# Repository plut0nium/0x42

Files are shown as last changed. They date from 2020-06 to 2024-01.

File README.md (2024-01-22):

# >__0x42___

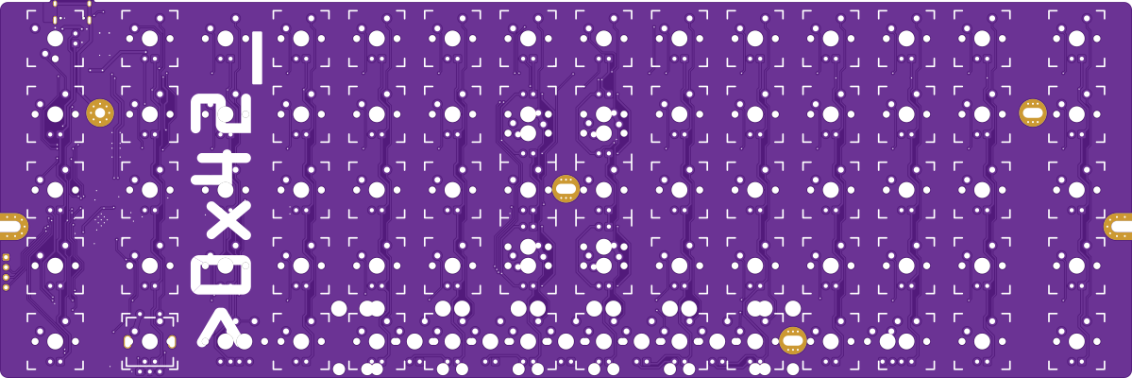
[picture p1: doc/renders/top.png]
0x42 top render

_Render generated by the [tracespace.io](https://tracespace.io/view/) site._

> **DISCLAIMER :**
> This PCB has been designed with Kicad6 and prototyped in late 2022.
> As of December 2023, I use Kicad7 and have converted the files to the new revised format.
> This is not expected to introduce any bug, but I do not offer any guarantee against it and provide the files AS-IS.
> You are therefore advised to perform an in-depth review of the design before manufacturing/assembly.

## Introduction
__0x42__ is an open-source 60% ortholinear keyboard PCB designed to fit the (_de facto_) standard 60% keyboard cases and use an ergo keycap set (1u alphas, with 1.5u modifiers and -optional- split 2u spacebars).

Heavily inspired by the [Boardwalk][boardwalk-url] (although the variety of supported layouts is much lower, see below), __0x42__ is based on a Raspberry Pi RP2040 (ARM) MCU with onboard USB-C connexion (or through a daughterboard), it allows the use of a rotary encoder and has a dedicated LED driver for in-switch backlight (monochrome).

## Features

 * MX-style switches
 * Standard 60% format
 * In-switch LED backlight using dedicated (_Lumissil_) LED driver
 * Rotary encoder
 * __No__ RGB underglow
 * USB Type-C with ESD protection _or_ USB daughterboard (through JST connector)
 * Powered by [QMK][qmk-url] (but could be ported to any other open-source MK firmware)

## Supported layouts

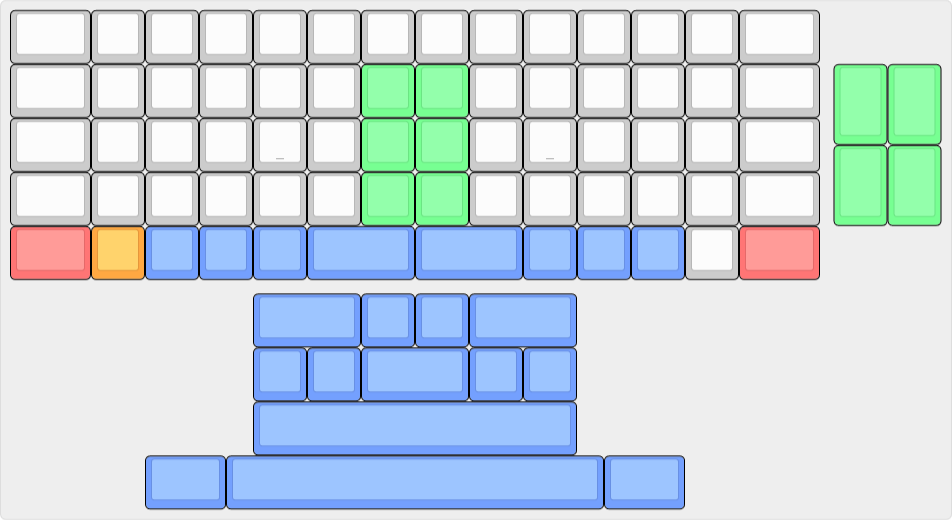
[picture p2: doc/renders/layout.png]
0x42 layouts

_Blue_ keys show some possible combinations of spacebars, _Orange_ can be replaced by rotary encoder, _Green_ are vertical (ergodox-like) 1.5u modifiers, and _Red_ are optional for HHKB-like layout.

## Keyboard cases

Please note that due to the ortholinear layout, some mounting holes on the PCB had to be moved (the 2 in the center part of the PCB), and consequently will not align with the standoffs commonly found in 60% tray-mount cases.
Only the 4 outer mounting holes are available in such situation.
This nevertheless results in a good fixation, particularly if using a switch plate, and should not be an issue for most users.

Other mounting types should not be affected.

## QMK Support

_TODO: add link to QMK repo_

## PCB Manufacturing & Assembly

### Panelization

[Kikit][kikit-url] can be used to produce a panelized PCB.

The included configuration in `0x42_panelize.json` will produce a single-board panel, i.e. adding a 10mm frame with tabs and mousebites.
This is not strictly required, but provides extra room for tooling holes, as well as order number placement.

```
kikit panelize -p 0x42_panelize.json 0x42.kicad_pcb panel/0x42_panel.kicad_pcb
```

### BOM

The schematic symbols have a "LCSC" property with LCSC/JLCPCB part # for suggested component reference.
As far as possible, JLCPCB _basic parts_ have been selected.
Some Kicad plugins make use of this information to extract a *.CSV BOM file that can be used for assembly.

There are many alternative references for compatible NOR flash chips, with varying capacity, from 8 to 32 Mbit or even more (note that RP2040 has a limit of 128Mbit/16MB)...

### JLCPCB

The [Kicad JLCPCB Tools][kicad-jlcpcb-url] plugin has been used to produce the required files (Gerber, drill, BOM & CPL) to have the board manufactured and assembled by JLCPCB. 

Kikit can also be used for this purpose, using `kikit fab`.

## License

CC-BY-SA 4.0

## Versions

 * __Rev 2__ _(work in progress)_ is almost identical to Rev 1, with MiniMELF diodes
 * __Rev 1__ is based on Raspberry Pi RP2040 MCU
 * __Rev 0__ is the original design and was based on a STM32F072 MCU

## Credits

 * [Boardwalk][boardwalk-url] by AlexAtPanc, Shensmobile & others... main source of inspiration for this layout
 * [Ai03][ai03-url], [Acheron Project/Gondolindrim][acheron-url], [ebastler][ebastler-url] for providing excellent opensource reference designs
 * and more generaly the mech keyboard community...

<!-- Markdwon links -->
[qmk-url]: https://qmk.fm/
[boardwalk-url]: https://panc.co/boardwalk
[ai03-url]: https://github.com/ai03-2725
[acheron-url]: https://github.com/AcheronProject
[ebastler-url]: https://github.com/ebastler
[kikit-url]: https://yaqwsx.github.io/KiKit/
[kicad-jlcpcb-url]: https://github.com/Bouni/kicad-jlcpcb-tools

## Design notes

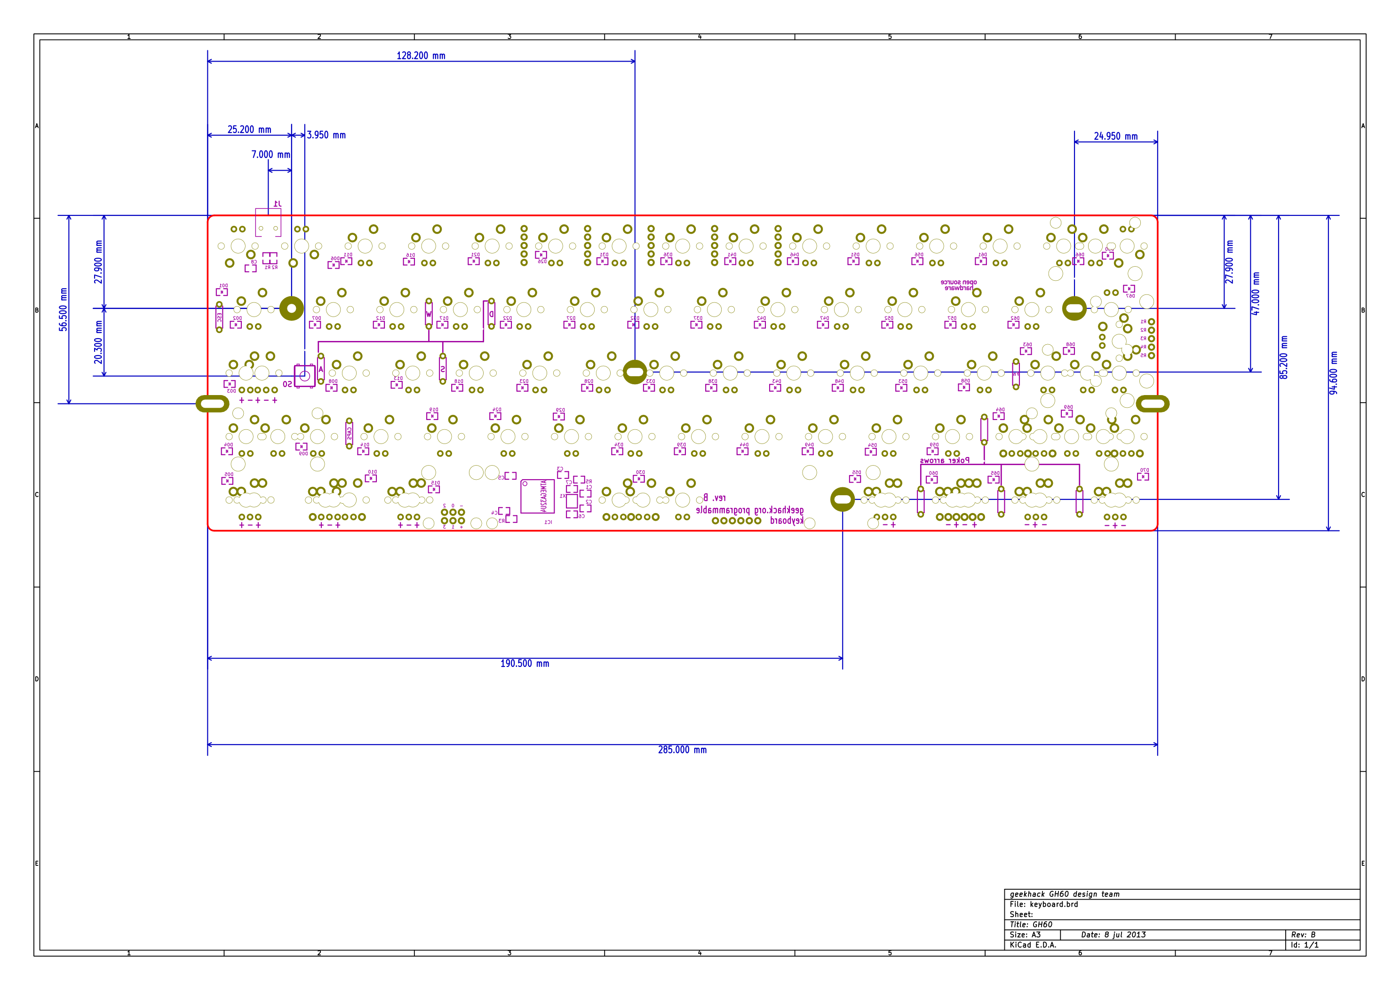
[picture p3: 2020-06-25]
doc/GH60_dimensions.png

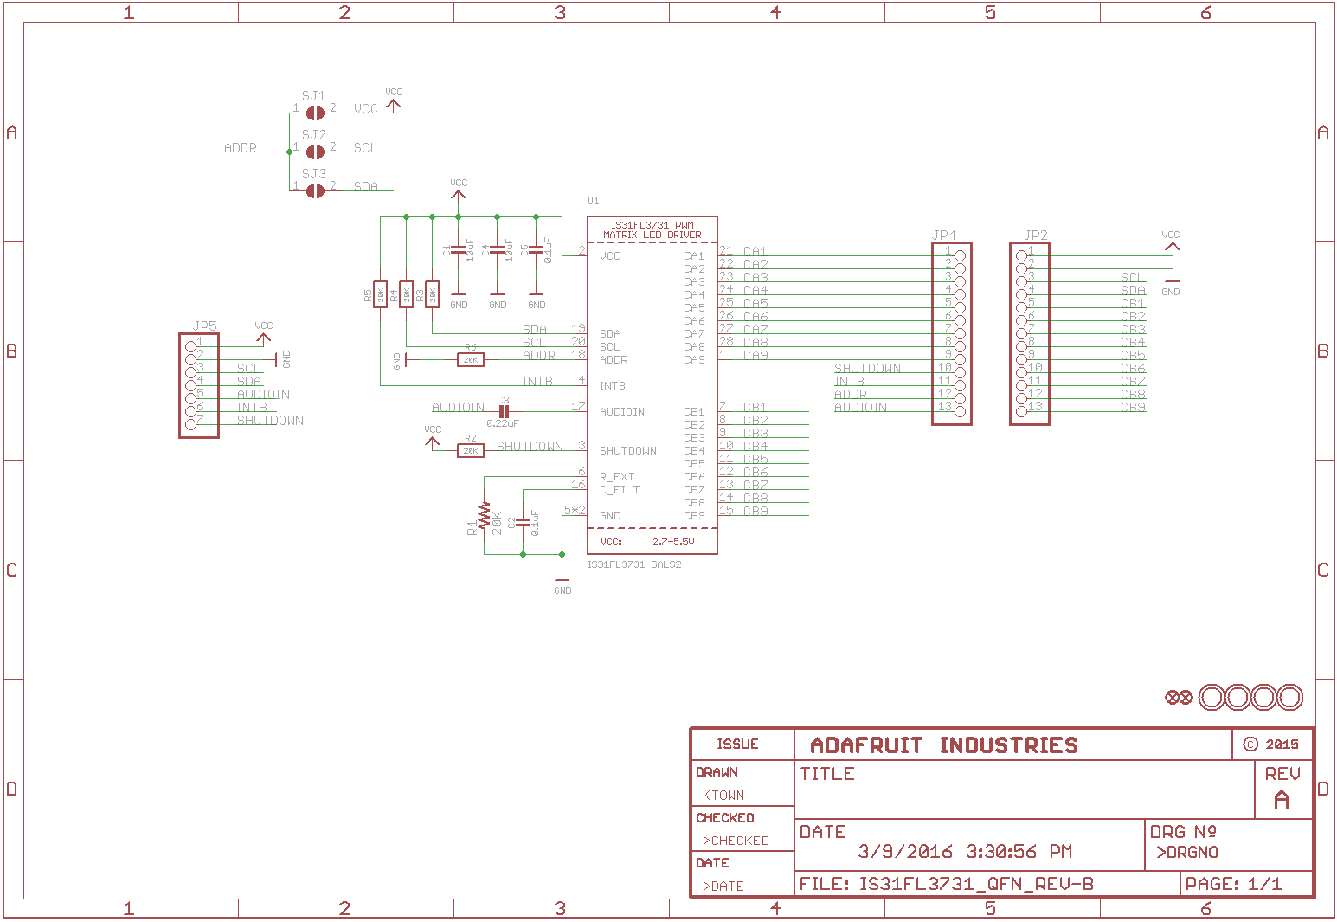
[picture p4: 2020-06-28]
doc/led_matrix_schem.png

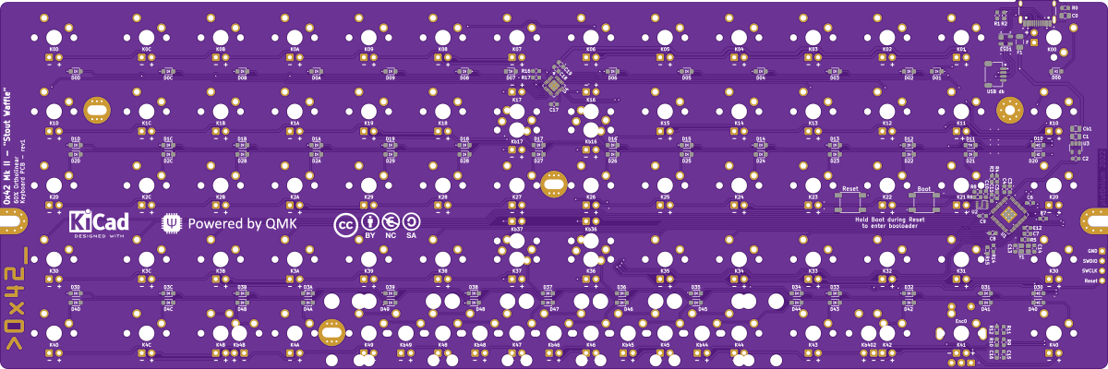
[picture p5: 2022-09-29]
doc/renders/bottom.png

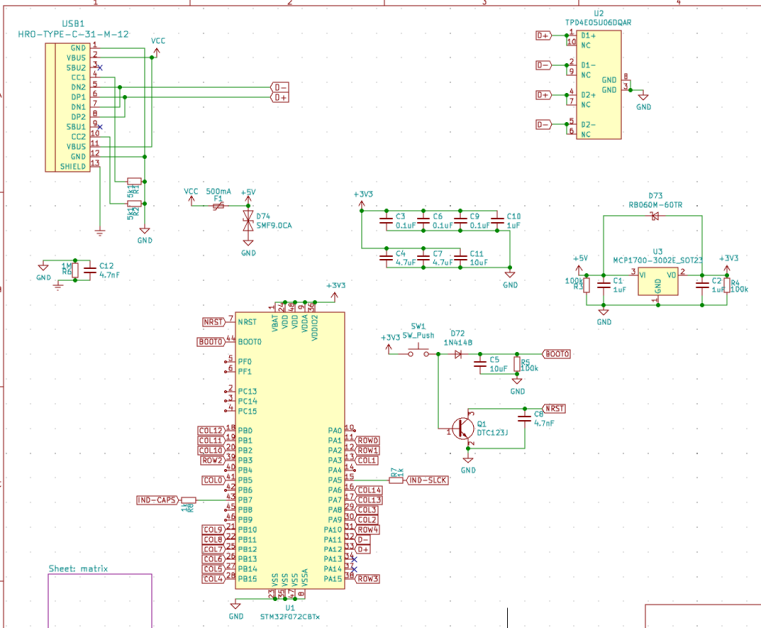
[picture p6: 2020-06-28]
doc/stm32_schem.png

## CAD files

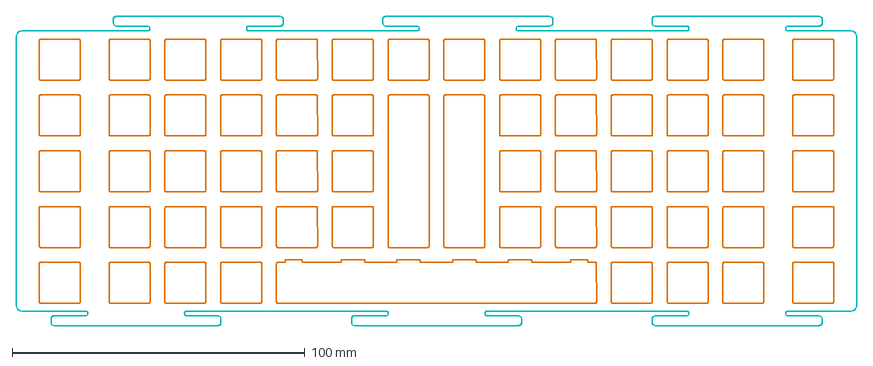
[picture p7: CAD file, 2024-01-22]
cad/plate_0x42_ALL.dxf
287.0 x 105.5 mm

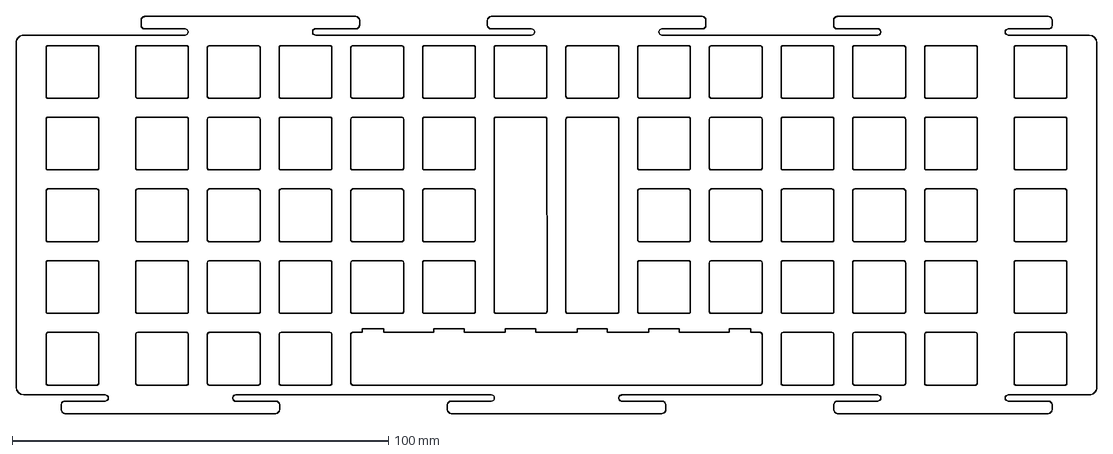
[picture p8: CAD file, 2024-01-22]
cad/plate_0x42_d60lite.dxf
287.0 x 105.5 mm

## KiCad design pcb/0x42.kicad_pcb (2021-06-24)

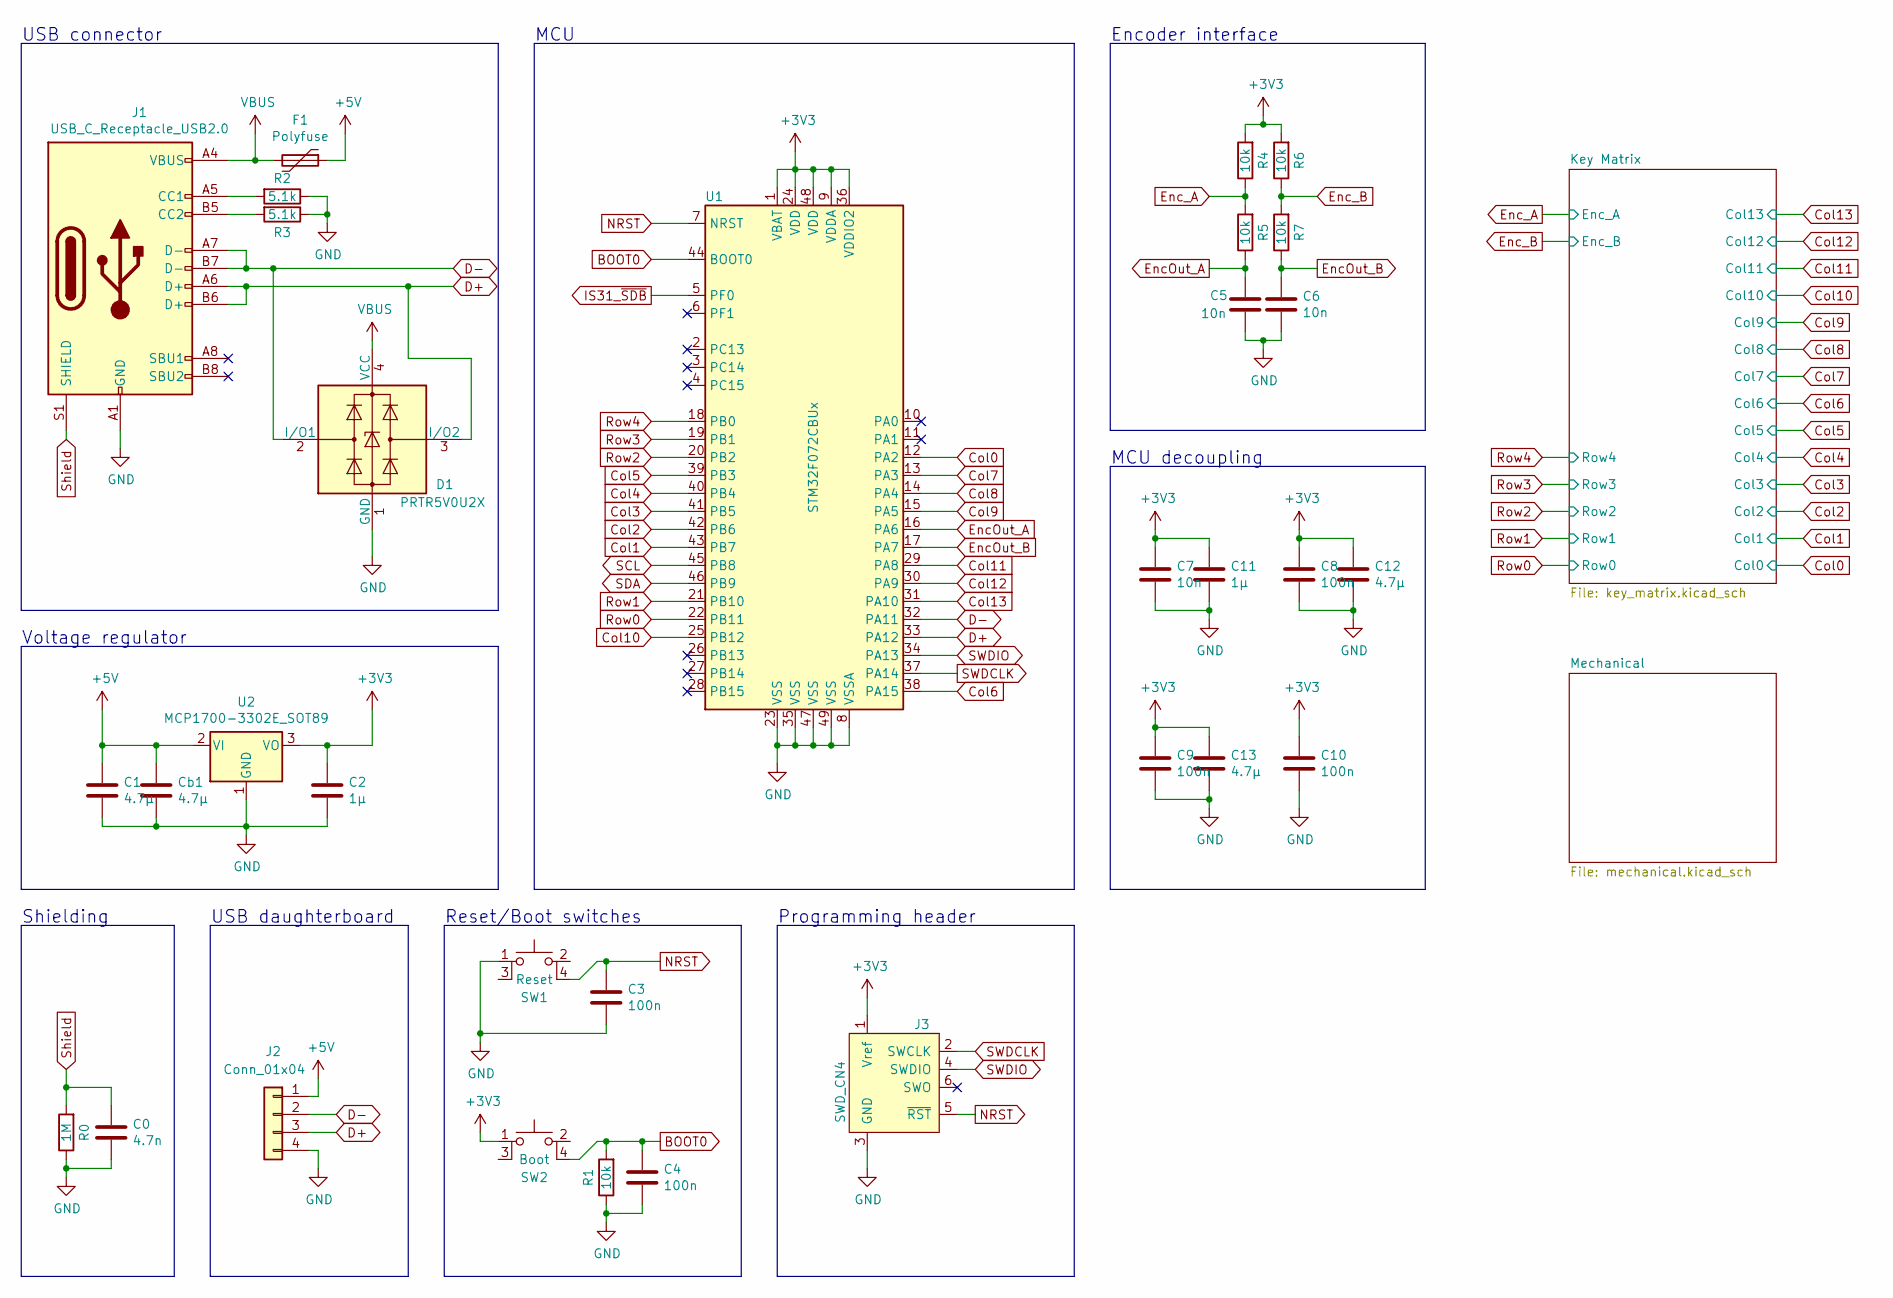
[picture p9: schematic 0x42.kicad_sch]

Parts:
C0: 4.7n; C_0805_2012Metric
C1: 4.7µ; C_0805_2012Metric
C2, C11: 1µ; C_0603_1608Metric
C3, C4, C8, C9, C10: 100n; C_0603_1608Metric
C5, C6, C7: 10n; C_0603_1608Metric
C12, C13: 4.7µ; C_0603_1608Metric
Cb1: 4.7µ; C_0805_2012Metric
D1: PRTR5V0U2X; SOT-143
F1: Polyfuse; Fuse_1206_3216Metric
J1: USB_C_Receptacle_USB2.0; USB_C_Receptacle_HRO_TYPE-C-31-M-12
J2: Conn_01x04; JST_SH_SM04B-SRSS-TB_1x04-1MP_P1.00mm_Horizontal
J3: SWD_CN4; SWD_1x06_P2.54mm_POGO
R0: 1M; R_0603_1608Metric
R1, R4, R5, R6, R7: 10k; R_0603_1608Metric
R2, R3: 5.1k; R_0603_1608Metric
SW1: Reset; TACT_SWITCH_5.2x5.2_4Pin
SW2: Boot; TACT_SWITCH_5.2x5.2_4Pin
U1: STM32F072CBUx; QFN-48-1EP_7x7mm_P0.5mm_EP5.6x5.6mm
U2: MCP1700-3302E_SOT89; SOT-89-3

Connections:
+3V3: C2.1, C7.1, C8.1, C9.1, C10.1, C11.1, C12.1, C13.1, J3.1 (Vref), R4.2, R6.2, SW2.1, U1.1 (VBAT), U1.9 (VDDA), U1.24 (VDD), U1.36 (VDDIO2), U1.48 (VDD), U2.3 (VO); also elsewhere on the board
+5V: C1.1, Cb1.1, F1.1, J2.1, U2.2 (VI); also elsewhere on the board
BOOT0: C4.1, R1.2, SW2.4, U1.44 (BOOT0)
Col0: U1.12 (PA2); also elsewhere on the board
Col1: U1.43 (PB7); also elsewhere on the board
Col2: U1.42 (PB6); also elsewhere on the board
Col3: U1.41 (PB5); also elsewhere on the board
Col4: U1.40 (PB4); also elsewhere on the board
Col5: U1.39 (PB3); also elsewhere on the board
Col6: U1.38 (PA15); also elsewhere on the board
Col7: U1.13 (PA3); also elsewhere on the board
Col8: U1.14 (PA4); also elsewhere on the board
Col9: U1.15 (PA5); also elsewhere on the board
Col10: U1.25 (PB12); also elsewhere on the board
Col11: U1.29 (PA8); also elsewhere on the board
Col12: U1.30 (PA9); also elsewhere on the board
Col13: U1.31 (PA10); also elsewhere on the board
D+: D1.3 (I/O2), J1.A6 (D+), J1.B6 (D+), J2.3, U1.33 (PA12)
D-: D1.2 (I/O1), J1.A7 (D-), J1.B7 (D-), J2.2, U1.32 (PA11)
EncOut_A: C5.1, R5.1, U1.16 (PA6)
EncOut_B: C6.1, R7.1, U1.17 (PA7)
Enc_A: R4.1, R5.2; also elsewhere on the board
Enc_B: R6.1, R7.2; also elsewhere on the board
GND: C0.2, C1.2, C2.2, C3.2, C4.2, C5.2, C6.2, C7.2, C8.2, C9.2, C10.2, C11.2, C12.2, C13.2, Cb1.2, D1.1 (GND), J1.A1 (GND), J1.A12 (GND), J1.B1 (GND), J1.B12 (GND), J2.4, J3.3 (GND), R0.1, R1.1, R2.1, R3.1, SW1.1, U1.8 (VSSA), U1.23 (VSS), U1.35 (VSS), U1.47 (VSS), U1.49 (VSS), U2.1 (GND); also elsewhere on the board
IS31_~SDB: U1.5 (PF0); also elsewhere on the board
NRST: C3.1, J3.5 (~RST), SW1.4, U1.7 (NRST)
unnamed: J1.A5 (CC1), R2.2
unnamed: J1.B5 (CC2), R3.2
RGB_DOUT: U1.28 (PB15); also elsewhere on the board
Row0: U1.22 (PB11); also elsewhere on the board
Row1: U1.21 (PB10); also elsewhere on the board
Row2: U1.20 (PB2); also elsewhere on the board
Row3: U1.19 (PB1); also elsewhere on the board
Row4: U1.18 (PB0); also elsewhere on the board
SCL: U1.45 (PB8); also elsewhere on the board
SDA: U1.46 (PB9); also elsewhere on the board
SWDCLK: J3.2 (SWCLK), U1.37 (PA14)
SWDIO: J3.4 (SWDIO), U1.34 (PA13)
Shield: C0.1, J1.S1 (SHIELD), R0.2; also elsewhere on the board
VBUS: D1.4 (VCC), F1.2, J1.A4 (VBUS), J1.A9 (VBUS), J1.B4 (VBUS), J1.B9 (VBUS)

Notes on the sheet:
USB daughterboard
Reset/Boot switches
Encoder interface
Programming header
MCU decoupling
MCU
Voltage regulator
USB connector
Shielding

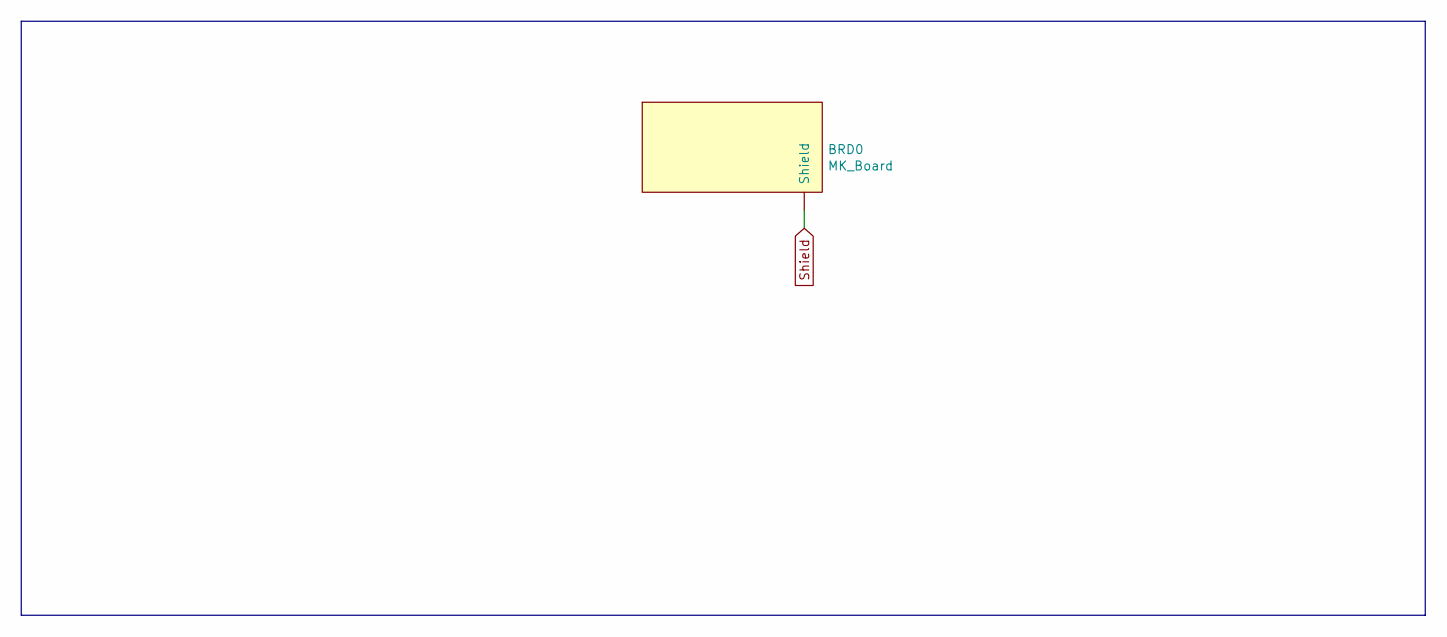
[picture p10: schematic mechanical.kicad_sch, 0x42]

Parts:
BRD0: MK_Board; 60_Outline_Ortho

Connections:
Shield: BRD0.1; also elsewhere on the board

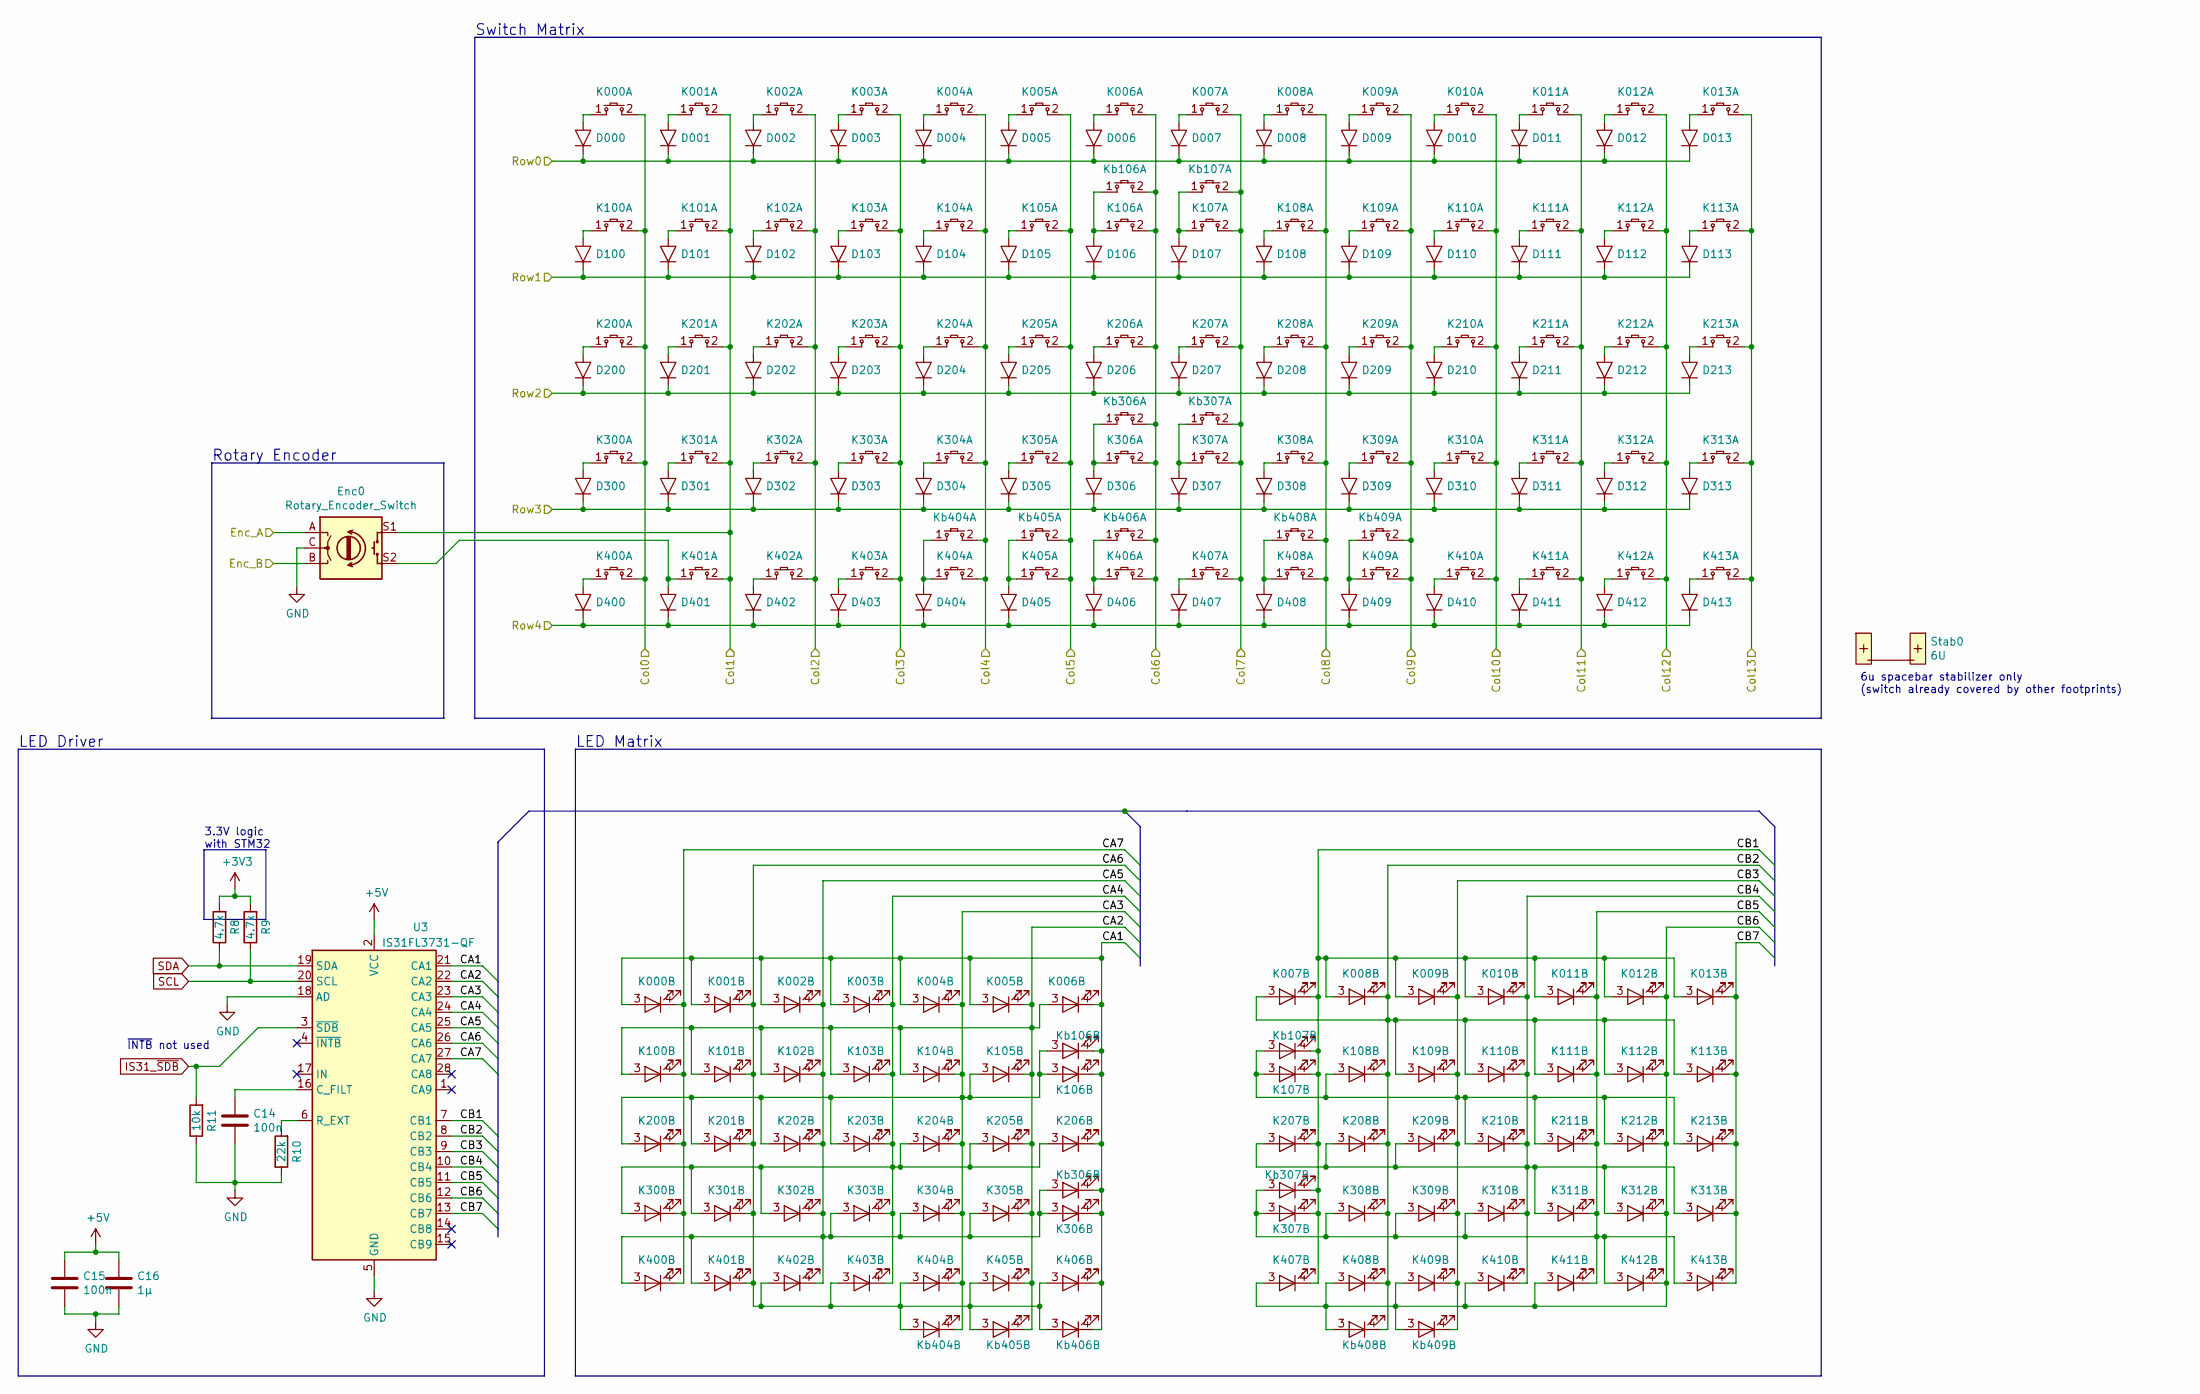
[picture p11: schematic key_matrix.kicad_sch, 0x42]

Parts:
C14, C15: 100n; C_0603_1608Metric
C16: 1µ; C_0603_1608Metric
D000, D001, D002, D003, D004, D005, D006, D007, D008, D009, D010, D011, D012, D013, D100, D101, D102, D103, D104, D105, D106, D107, D108, D109, D110, D111, D112, D113, D200, D201, D202, D203, D204, D205, D206, D207, D208, D209, D210, D211, D212, D213, D300, D301, D302, D303, D304, D305, D306, D307, D308, D309, D310, D311, D312, D313, D400, D401, D402, D403, D404, D405, D406, D407, D408, D409, D410, D411, D412, D413: Diode; D_SOD-323
Enc0: Rotary_Encoder_Switch; RotaryEncoder_Alps_EC11E-Switch_Vertical
K000: 1.5U; MXOnly-1.5U-Vertical-Flipped
K001, K002, K003, K004, K005, K006, K007, K008, K009, K010, K011, K012, K101, K102, K103, K104, K105, K108, K109, K110, K111, K112, K201, K202, K203, K204, K205, K206, K207, K208, K209, K210, K211, K212, K301, K302, K303, K304, K305, K306, K307, K308, K309, K310, K311, K312, K401, K402, K403, K404, K405, K406, K407, K408, K409, K410, K411, K412: 1U; MXOnly-1U
K013, K100, K113, K200, K213, K300, K313, K400, K413: 1.5U; MXOnly-1.5U
K106, K107: 1U; MXOnly-1U-Flipped
Kb106, Kb107: 1.5U; MXOnly-1.5U-Vertical
Kb306, Kb307: 1.5U; MXOnly-1.5U-Vertical-Flipped
Kb404, Kb405, Kb406, Kb408, Kb409: 2U; MXOnly-2U-ReversedStabilizers
R8, R9: 4.7k; R_0603_1608Metric
R10: 22k; R_0603_1608Metric
R11: 10k; R_0603_1608Metric
Stab0: 6U; MXOnly-6U-ReversedStabilizersOnly
U3: IS31FL3731-QF; QFN-28-1EP_4x4mm_P0.4mm_EP2.3x2.3mm

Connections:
+3V3: R8.2, R9.2; also elsewhere on the board
+5V: C15.1, C16.1, U3.2 (VCC); also elsewhere on the board
/Key Matrix/CA1: K000.3 (A), K001.3 (A), K002.3 (A), K003.3 (A), K004.3 (A), K005.3 (A), K006.4 (K), K106.4 (K), K206.4 (K), K306.4 (K), K406.4 (K), Kb106.4 (K), Kb306.4 (K), Kb406.4 (K), U3.21 (CA1)
/Key Matrix/CA2: K005.4 (K), K006.3 (A), K100.3 (A), K101.3 (A), K102.3 (A), K103.3 (A), K104.3 (A), K105.4 (K), K205.4 (K), K305.4 (K), K405.4 (K), Kb405.4 (K), U3.22 (CA2)
/Key Matrix/CA3: K004.4 (K), K104.4 (K), K105.3 (A), K106.3 (A), K200.3 (A), K201.3 (A), K202.3 (A), K203.3 (A), K204.4 (K), K304.4 (K), K404.4 (K), Kb106.3 (A), Kb404.4 (K), U3.23 (CA3)
/Key Matrix/CA4: K003.4 (K), K103.4 (K), K203.4 (K), K204.3 (A), K205.3 (A), K206.3 (A), K300.3 (A), K301.3 (A), K302.3 (A), K303.4 (K), K403.4 (K), U3.24 (CA4)
/Key Matrix/CA5: K002.4 (K), K102.4 (K), K202.4 (K), K302.4 (K), K303.3 (A), K304.3 (A), K305.3 (A), K306.3 (A), K400.3 (A), K401.3 (A), K402.4 (K), Kb306.3 (A), U3.25 (CA5)
/Key Matrix/CA6: K001.4 (K), K101.4 (K), K201.4 (K), K301.4 (K), K401.4 (K), K402.3 (A), K403.3 (A), K404.3 (A), K405.3 (A), K406.3 (A), Kb404.3 (A), Kb405.3 (A), Kb406.3 (A), U3.26 (CA6)
/Key Matrix/CA7: K000.4 (K), K100.4 (K), K200.4 (K), K300.4 (K), K400.4 (K), U3.27 (CA7)
/Key Matrix/CB1: K007.4 (K), K008.3 (A), K009.3 (A), K010.3 (A), K011.3 (A), K012.3 (A), K013.3 (A), K107.4 (K), K207.4 (K), K307.4 (K), K407.4 (K), Kb107.4 (K), Kb307.4 (K), U3.7 (CB1)
/Key Matrix/CB2: K007.3 (A), K008.4 (K), K108.4 (K), K109.3 (A), K110.3 (A), K111.3 (A), K112.3 (A), K113.3 (A), K208.4 (K), K308.4 (K), K408.4 (K), Kb408.4 (K), U3.8 (CB2)
/Key Matrix/CB3: K009.4 (K), K107.3 (A), K108.3 (A), K109.4 (K), K209.4 (K), K210.3 (A), K211.3 (A), K212.3 (A), K213.3 (A), K309.4 (K), K409.4 (K), Kb107.3 (A), Kb409.4 (K), U3.9 (CB3)
/Key Matrix/CB4: K010.4 (K), K110.4 (K), K207.3 (A), K208.3 (A), K209.3 (A), K210.4 (K), K310.4 (K), K311.3 (A), K312.3 (A), K313.3 (A), K410.4 (K), U3.10 (CB4)
/Key Matrix/CB5: K011.4 (K), K111.4 (K), K211.4 (K), K307.3 (A), K308.3 (A), K309.3 (A), K310.3 (A), K311.4 (K), K411.4 (K), K412.3 (A), K413.3 (A), Kb307.3 (A), U3.11 (CB5)
/Key Matrix/CB6: K012.4 (K), K112.4 (K), K212.4 (K), K312.4 (K), K407.3 (A), K408.3 (A), K409.3 (A), K410.3 (A), K411.3 (A), K412.4 (K), Kb408.3 (A), Kb409.3 (A), U3.12 (CB6)
/Key Matrix/CB7: K013.4 (K), K113.4 (K), K213.4 (K), K313.4 (K), K413.4 (K), U3.13 (CB7)
Col0: K000.2, K100.2, K200.2, K300.2, K400.2; also elsewhere on the board
Col1: Enc0.S1, K001.2, K101.2, K201.2, K301.2, K401.2; also elsewhere on the board
Col2: K002.2, K102.2, K202.2, K302.2, K402.2; also elsewhere on the board
Col3: K003.2, K103.2, K203.2, K303.2, K403.2; also elsewhere on the board
Col4: K004.2, K104.2, K204.2, K304.2, K404.2, Kb404.2; also elsewhere on the board
Col5: K005.2, K105.2, K205.2, K305.2, K405.2, Kb405.2; also elsewhere on the board
Col6: K006.2, K106.2, K206.2, K306.2, K406.2, Kb106.2, Kb306.2, Kb406.2; also elsewhere on the board
Col7: K007.2, K107.2, K207.2, K307.2, K407.2, Kb107.2, Kb307.2; also elsewhere on the board
Col8: K008.2, K108.2, K208.2, K308.2, K408.2, Kb408.2; also elsewhere on the board
Col9: K009.2, K109.2, K209.2, K309.2, K409.2, Kb409.2; also elsewhere on the board
Col10: K010.2, K110.2, K210.2, K310.2, K410.2; also elsewhere on the board
Col11: K011.2, K111.2, K211.2, K311.2, K411.2; also elsewhere on the board
Col12: K012.2, K112.2, K212.2, K312.2, K412.2; also elsewhere on the board
Col13: K013.2, K113.2, K213.2, K313.2, K413.2; also elsewhere on the board
Enc_A: Enc0.A; also elsewhere on the board
Enc_B: Enc0.B; also elsewhere on the board
GND: C14.2, C15.2, C16.2, Enc0.C, R10.1, R11.1, U3.5 (GND), U3.18 (AD), U3.29 (GND); also elsewhere on the board
IS31_~SDB: R11.2, U3.3 (~SDB); also elsewhere on the board
unnamed: C14.1, U3.16 (C_FILT)
unnamed: D000.2 (A), K000.1
unnamed: D001.2 (A), K001.1
unnamed: D002.2 (A), K002.1
unnamed: D003.2 (A), K003.1
unnamed: D004.2 (A), K004.1
unnamed: D005.2 (A), K005.1
unnamed: D006.2 (A), K006.1
unnamed: D007.2 (A), K007.1
unnamed: D008.2 (A), K008.1
unnamed: D009.2 (A), K009.1
unnamed: D010.2 (A), K010.1
unnamed: D011.2 (A), K011.1
unnamed: D012.2 (A), K012.1
unnamed: D013.2 (A), K013.1
unnamed: D100.2 (A), K100.1
unnamed: D101.2 (A), K101.1
unnamed: D102.2 (A), K102.1
unnamed: D103.2 (A), K103.1
unnamed: D104.2 (A), K104.1
unnamed: D105.2 (A), K105.1
unnamed: D106.2 (A), K106.1, Kb106.1
unnamed: D107.2 (A), K107.1, Kb107.1
unnamed: D108.2 (A), K108.1
unnamed: D109.2 (A), K109.1
unnamed: D110.2 (A), K110.1
unnamed: D111.2 (A), K111.1
unnamed: D112.2 (A), K112.1
unnamed: D113.2 (A), K113.1
unnamed: D200.2 (A), K200.1
unnamed: D201.2 (A), K201.1
unnamed: D202.2 (A), K202.1
unnamed: D203.2 (A), K203.1
unnamed: D204.2 (A), K204.1
unnamed: D205.2 (A), K205.1
unnamed: D206.2 (A), K206.1
unnamed: D207.2 (A), K207.1
unnamed: D208.2 (A), K208.1
unnamed: D209.2 (A), K209.1
unnamed: D210.2 (A), K210.1
unnamed: D211.2 (A), K211.1
unnamed: D212.2 (A), K212.1
unnamed: D213.2 (A), K213.1
unnamed: D300.2 (A), K300.1
unnamed: D301.2 (A), K301.1
unnamed: D302.2 (A), K302.1
unnamed: D303.2 (A), K303.1
unnamed: D304.2 (A), K304.1
unnamed: D305.2 (A), K305.1
unnamed: D306.2 (A), K306.1, Kb306.1
unnamed: D307.2 (A), K307.1, Kb307.1
unnamed: D308.2 (A), K308.1
unnamed: D309.2 (A), K309.1
unnamed: D310.2 (A), K310.1
unnamed: D311.2 (A), K311.1
unnamed: D312.2 (A), K312.1
unnamed: D313.2 (A), K313.1
unnamed: D400.2 (A), K400.1
unnamed: D401.2 (A), Enc0.S2, K401.1
unnamed: D402.2 (A), K402.1
unnamed: D403.2 (A), K403.1
unnamed: D404.2 (A), K404.1, Kb404.1
unnamed: D405.2 (A), K405.1, Kb405.1
unnamed: D406.2 (A), K406.1, Kb406.1
unnamed: D407.2 (A), K407.1
unnamed: D408.2 (A), K408.1, Kb408.1
unnamed: D409.2 (A), K409.1, Kb409.1
unnamed: D410.2 (A), K410.1
unnamed: D411.2 (A), K411.1
unnamed: D412.2 (A), K412.1
unnamed: D413.2 (A), K413.1
unnamed: R10.2, U3.6 (R_EXT)
Row0: D000.1 (K), D001.1 (K), D002.1 (K), D003.1 (K), D004.1 (K), D005.1 (K), D006.1 (K), D007.1 (K), D008.1 (K), D009.1 (K), D010.1 (K), D011.1 (K), D012.1 (K), D013.1 (K); also elsewhere on the board
Row1: D100.1 (K), D101.1 (K), D102.1 (K), D103.1 (K), D104.1 (K), D105.1 (K), D106.1 (K), D107.1 (K), D108.1 (K), D109.1 (K), D110.1 (K), D111.1 (K), D112.1 (K), D113.1 (K); also elsewhere on the board
Row2: D200.1 (K), D201.1 (K), D202.1 (K), D203.1 (K), D204.1 (K), D205.1 (K), D206.1 (K), D207.1 (K), D208.1 (K), D209.1 (K), D210.1 (K), D211.1 (K), D212.1 (K), D213.1 (K); also elsewhere on the board
Row3: D300.1 (K), D301.1 (K), D302.1 (K), D303.1 (K), D304.1 (K), D305.1 (K), D306.1 (K), D307.1 (K), D308.1 (K), D309.1 (K), D310.1 (K), D311.1 (K), D312.1 (K), D313.1 (K); also elsewhere on the board
Row4: D400.1 (K), D401.1 (K), D402.1 (K), D403.1 (K), D404.1 (K), D405.1 (K), D406.1 (K), D407.1 (K), D408.1 (K), D409.1 (K), D410.1 (K), D411.1 (K), D412.1 (K), D413.1 (K); also elsewhere on the board
SCL: R9.1, U3.20 (SCL); also elsewhere on the board
SDA: R8.1, U3.19 (SDA); also elsewhere on the board

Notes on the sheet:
6u spacebar stabilizer only (switch already covered by other footprints)
Rotary Encoder
3.3V logic with STM32
LED Matrix
~{INTB} not used
LED Driver
Switch Matrix

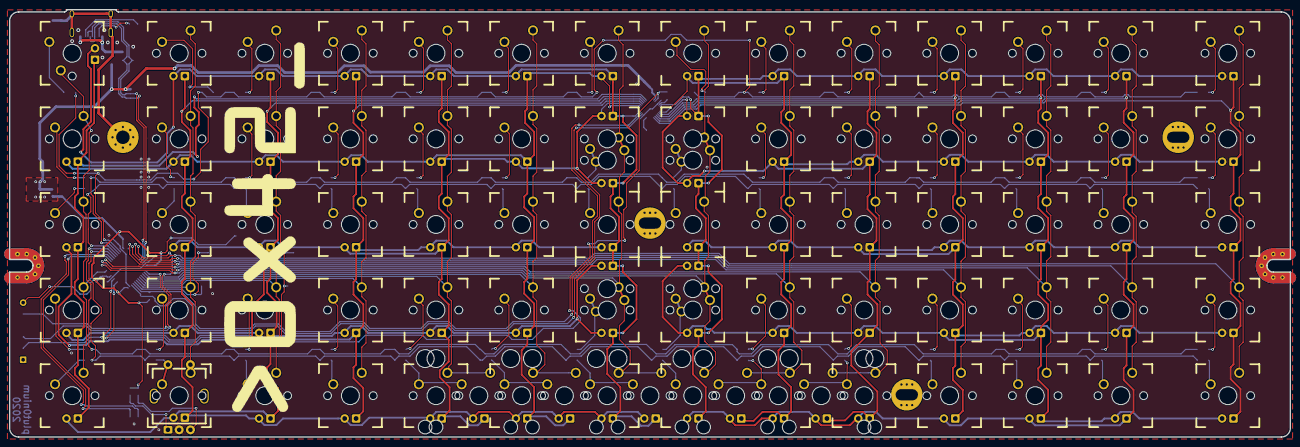
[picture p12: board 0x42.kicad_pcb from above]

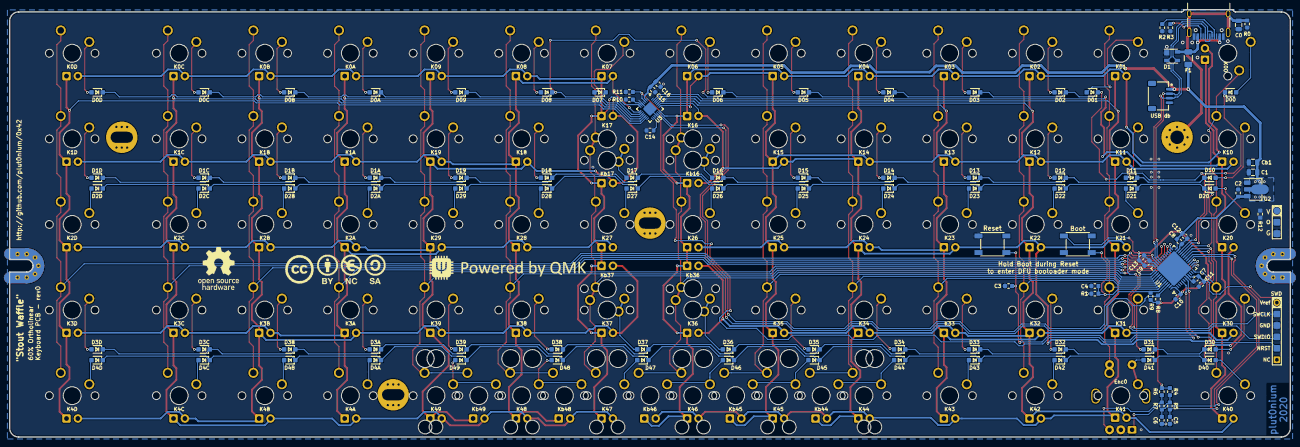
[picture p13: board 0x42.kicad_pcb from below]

Board: 2 copper layers, 285.0 x 95.1 mm, 194 parts (112 on the bottom side), 126 nets.

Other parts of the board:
J4: Conn_01x03; RGB_header_VoG_pads
R12: 4.7k; R_0603_1608Metric

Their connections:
+5V: J4.1, R12.2; also elsewhere on the board
GND: J4.3; also elsewhere on the board
RGB_DOUT: J4.2, R12.1; also elsewhere on the board

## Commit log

2020-06-25 V1: FET driven backlight + general layout
    [0x42.kicad_pcb, 0x42.sch, key_matrix.sch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]
2020-06-28 IS31 Led matrix
    [0x42.sch, leds.sch]
2020-06-28 STM32 documentation
2020-06-28 Start conversion to stm32
    [0x42.sch]
2020-09-03 Add doc (STM32 & ISSI)
2020-09-03 LTSpice simulation for reset circuitry
2020-09-03 Complete STM32 PCB v1
    [0x42.kicad_pcb, 0x42.sch, key_matrix.sch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]
2020-09-04 Wider IS31 supply trace
    [0x42.kicad_pcb]
2020-09-15 Replace 2x05pins SWD connector by 1x06 (Nucleo CN4 pinout)
    [0x42.kicad_pcb, 0x42.sch]
2020-09-16 Silkscreen work
    [0x42.kicad_pcb]
2020-09-16 Update Switches and Diodes references on silkscreen
    [0x42.kicad_pcb, key_matrix.sch]
2020-09-16 Ready for gerbers generation
    [0x42.kicad_pcb]
2020-09-16 Gerbers !
    [0x42-B_Cu.gbr, 0x42-B_Mask.gbr, 0x42-B_Paste.gbr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]
2020-10-06 Update to 5.1.7 and PCB metadata (revision)
    [0x42.kicad_pcb, 0x42.sch, key_matrix.sch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]
2020-10-06 Interactive HTML BOM
2021-06-24 Add RGB output - WiP
    [0x42.kicad_pcb, 0x42.sch, key_matrix.sch]
2022-09-17 Switch to Kicad6
    [0x42-B_Cu.gbr, 0x42-B_Mask.gbr, 0x42-B_Paste.gbr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]
2022-09-29 PCB silkscreen work - 0x42 drawings & footprints
2022-09-29 Switched to RP2040 - PCB finalization
    [0x42.kicad_sch, key_matrix.kicad_sch, mechanical.kicad_sch]
2022-09-29 Minor PCB & SilkS update
2023-11-06 Convert to Kicad 7
    [0x42.kicad_sch, key_matrix.kicad_sch, mechanical.kicad_sch]
2023-11-27 Remove outdated Rev0 html BOM
2023-12-29 Switch to MiniMELF (SOD-80) diodes
    [key_matrix.kicad_sch]
2023-12-29 remove outdated panelized PCB
    [0x42_panel-EdgeCuts.gbr, 0x42_panel-MaskBottom.gbr, 0x42_panel-MaskTop.gbr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]
2023-12-30 Add kicad *.lck files to .gitignore
2023-12-30 Update BOM information
    [0x42.kicad_sch, key_matrix.kicad_sch]
2023-12-30 Update PCB assembly information (mostly part reference numbers)
    [0x42.kicad_sch]
2023-12-31 solved some schematic <> pcb inconsistencies on the encoder interface
    [0x42.kicad_sch, key_matrix.kicad_sch]
2024-01-22 Update I2C pullups + minor PCB changes
    [key_matrix.kicad_sch]
2024-01-22 Silscreen work - update license footprint
2024-01-22 Add CAD files (switch plates)
    [plate_0x42_ALL.dxf, plate_0x42_d60lite.dxf]
2024-03-05 Update to Kicad 8.0
    [0x42.kicad_sch, key_matrix.kicad_sch, mechanical.kicad_sch]
2024-03-05 Update DoNotPopulate property for optionnal components (except switches)
    [0x42.kicad_sch, key_matrix.kicad_sch]
2024-03-05 Bump revision number to 2.1
    [0x42.kicad_sch, key_matrix.kicad_sch, mechanical.kicad_sch]
2024-07-05 Bump to Kicad 8.0.3
    [0x42.kicad_sch, key_matrix.kicad_sch, mechanical.kicad_sch]
2024-07-05 Alternate LCSC Part # for LL4148
    [key_matrix.kicad_sch]
2024-07-06 Minor PCB (vias) & Silkscreen
